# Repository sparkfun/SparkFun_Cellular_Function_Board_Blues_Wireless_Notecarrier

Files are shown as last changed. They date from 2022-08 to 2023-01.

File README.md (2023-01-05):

SparkFun MicroMod Cellular Function Board - Blues Wireless Notecarrier
===========================================================

SparkFun MicroMod Cellular Function Board Blues Wireless Notecarrier (https://www.sparkfun.com/products/20409)

[*SparkFun MicroMod Cellular Function Board - Blues Wireless Notecarrier (WRL-20409)*](https://www.sparkfun.com/products/20409)

A MicroMod Function Board that works as a Blues Wireless Notecarrier featuring the Notecard - NOTE-NBGL-500. This Function Board adds a cellular module to the MicroMod ecosystem allowing users to send and receive data from anywhere with a compatible cellular signal. The Notecard has a built-in SIM card and includes a 10 year subscription and 500MB of data included in the price. An onboard nano SIM slot is provided for users who prefer or need to use their own SIM. The Notecard module also comes with integrated cellular, SIM, onboard GPS, 3-axis accelerometer with an on-chip temperature sensor. On top of that, the Notecard features outboard device firmware updates (DFU) meaning you can reprogram a connected Processor remotely through Blues' Notehub service! There are some limitations to this process so make sure to read through the Outboard documentation in the SparkFun Hookup Guide for more information on how to properly perform Outboard device firmware updates. 

Repository Contents
-------------------

* **/Firmware/examples**
* **/Hardware**

Documentation
-------------

* **[Hookup Guide](https://learn.sparkfun.com/tutorials/cellular-function-board---blues-wireless-notecarrier)** - A standard Hookup Guide to get started with the MicroMod Cellular Function Board - Blues Wireless Notecarrier.

Product Versions
----------------

* [WRL-20409](https://www.sparkfun.com/products/20409) - Initial Release

Version History
---------------

* v1.0 - Initial release

License Information
-------------------

This product is _**open source**_! 

Please review the LICENSE.md file for license information. 

If you have any questions or concerns on licensing, please contact technical support on our [SparkFun forums](https://forum.sparkfun.com/viewforum.php?f=152).

Distributed as-is; no warranty is given.

- Your friends at SparkFun.

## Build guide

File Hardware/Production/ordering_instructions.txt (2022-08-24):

panel size, 128x137mm
PCB thickness, 0.8mm
number of layers, 2
bevel, Gold Fingers + 45° Finger Chamfered
soldermask color, Red
silkscreen color, White
oz copper, 1oz
finish, ENIG
stencils, none
pcs per panel, 6
min trace width, 0.1100mm / 0.0043in
min drill size, 0.3000mm / 0.0118in

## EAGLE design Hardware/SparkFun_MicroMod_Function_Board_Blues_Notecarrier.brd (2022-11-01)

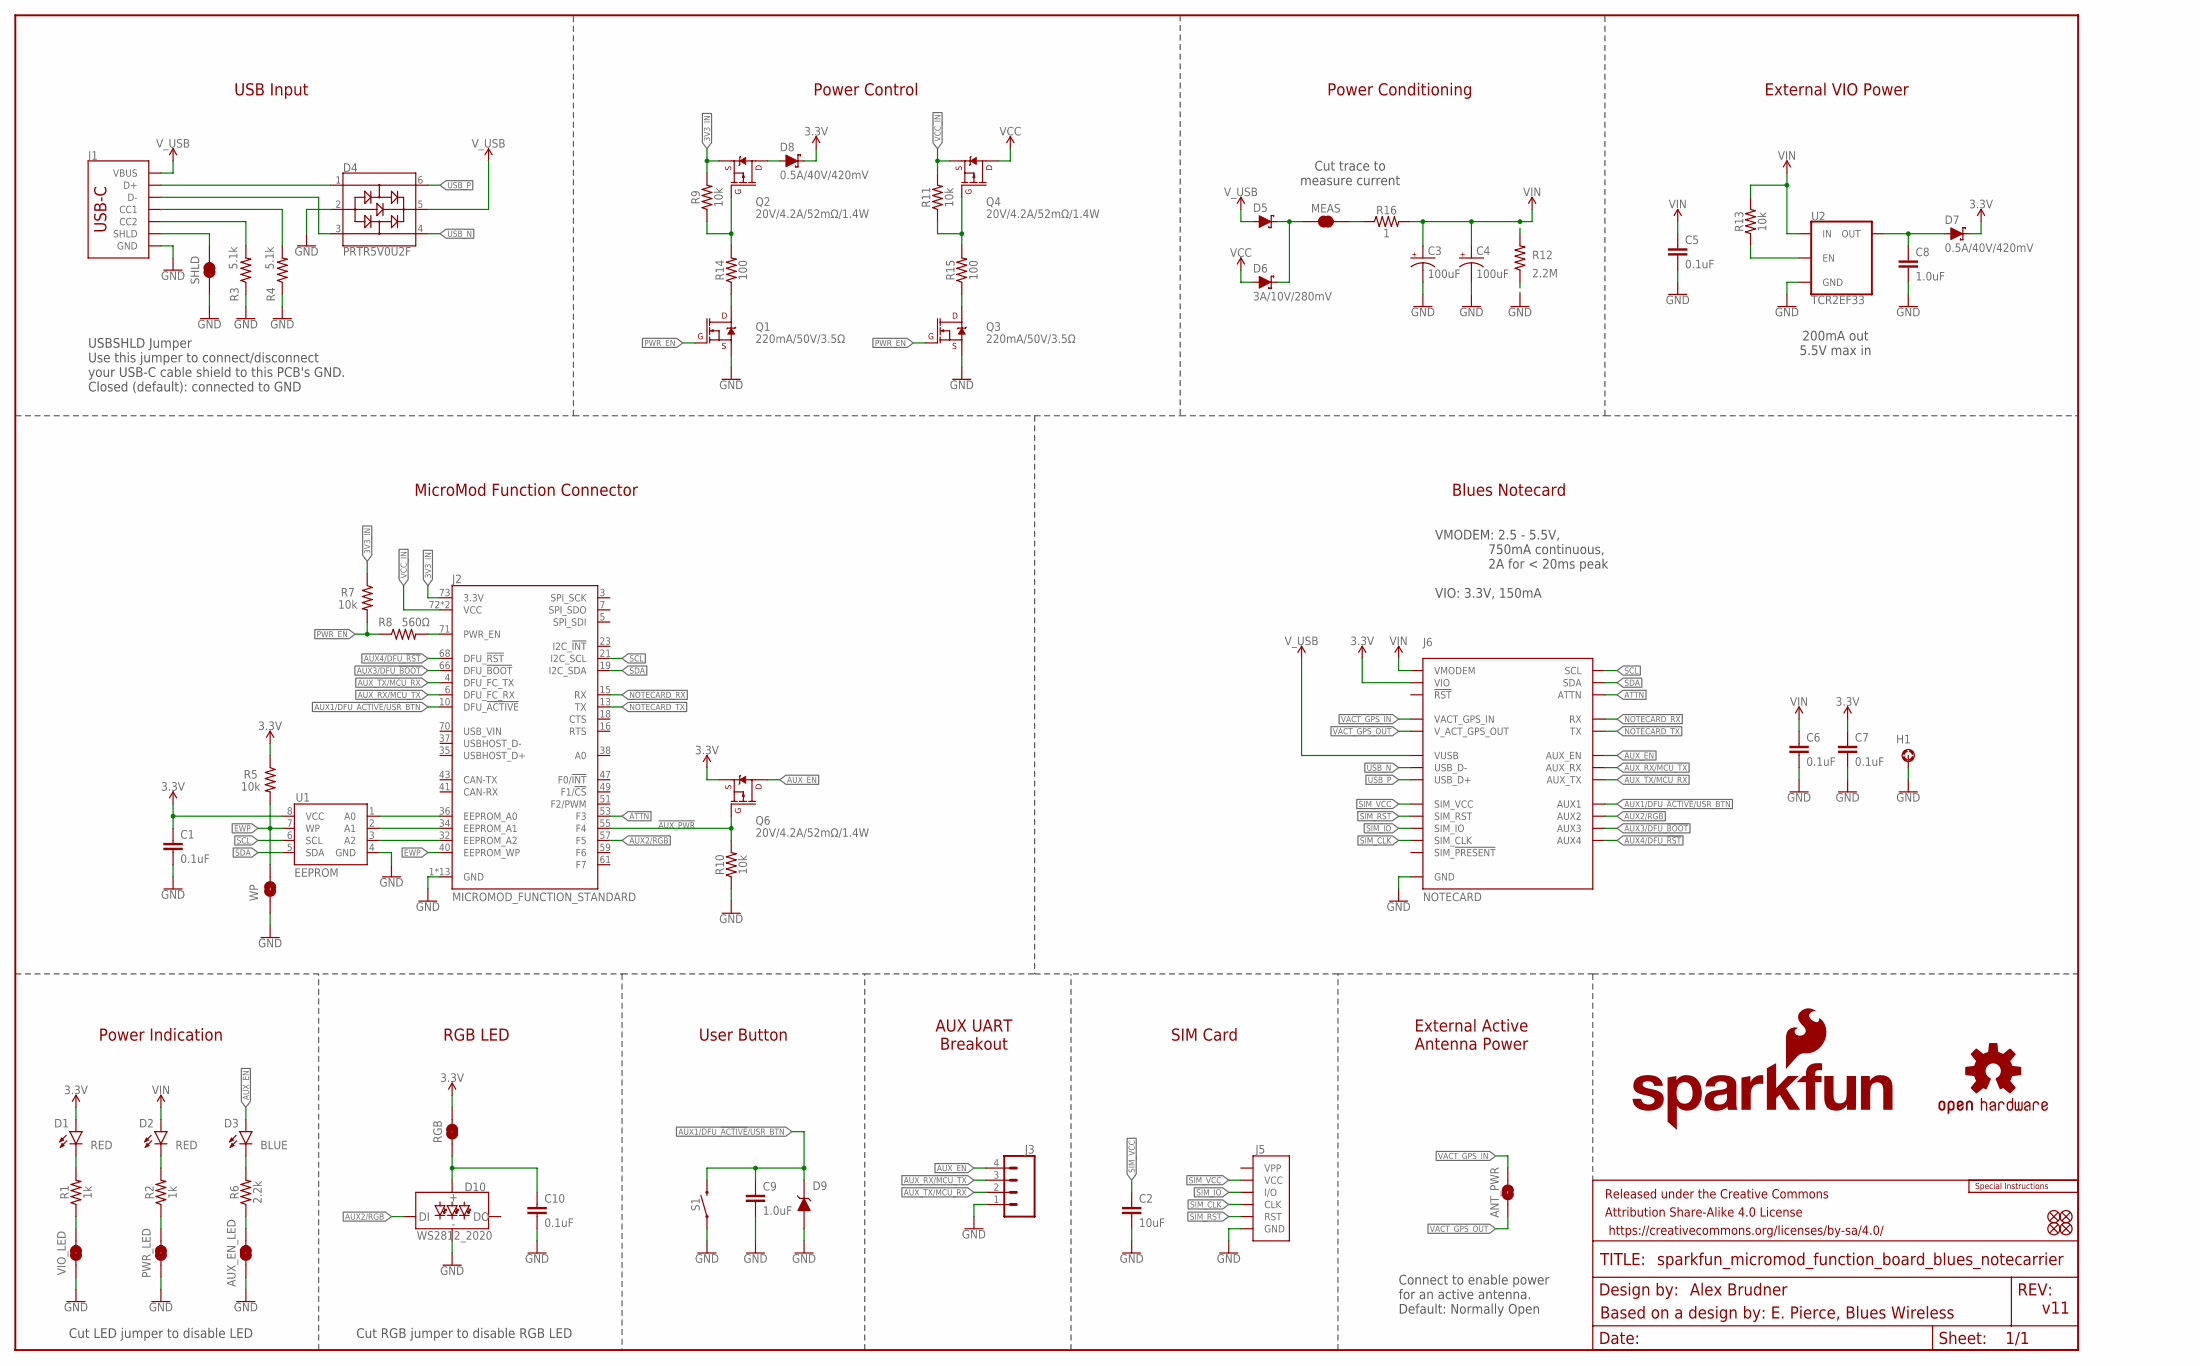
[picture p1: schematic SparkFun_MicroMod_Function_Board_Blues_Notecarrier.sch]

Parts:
ANT_PWR: JUMPER-SMT_2_NO_SILK; SMT-JUMPER_2_NO_SILK
AUX_EN_LED: JUMPER-SMT_2_NC_TRACE_SILK; SMT-JUMPER_2_NC_TRACE_SILK
C1, C5, C6, C7, C10: 0.1uF; 0402-TIGHT
C2: 10uF; 0805
C3, C4: 100uF; PANASONIC_D
C8, C9: 1.0uF; 0402-TIGHT
D1, D2: RED; LED-0603
D3: BLUE; LED-0603
D4: PRTR5V0U2F; SOT886
D5, D6: 3A/10V/280mV; SOD-323
D7, D8: 0.5A/40V/420mV; SOD-323
D9: SMBJP6KE-DNP; DO-214AA
D10: WS2812_2020; WS2812-2020
FD1, FD2, FD3, FD4: FIDUCIALUFIDUCIAL; FIDUCIAL-MICRO
FRAME1: FRAME-LEDGER; CREATIVE_COMMONS
H1: STAND-OFF-REFLOW-M2.5_2.5MM_TALL; STAND-OFF-REFLOW-M2.5
J1: USB_C_2-LAYER_PADS; USB-C-16P-2LAYER-PADS
J2: MICROMOD_FUNCTION_STANDARD; M.2-CARD-E-22_FUNCTION_STANDARD
J3: CONN_041X04_NO_SILK_NO_POP; 1X04_NO_SILK
J5: SIMHOLDER-NANOSIM-MOLEX; NANO_SIM_MOLEX_104224-0820
J6: NOTECARD; M.2-CONNECTOR-E
LOGO1: SFE_LOGO_NAME_FLAME.1_INCH; SFE_LOGO_NAME_FLAME_.1
LOGO2: SPECIAL_INSTRUCTIONS-ORDERING; ORDERING_INSTRUCTIONS
LOGO3: OSHW-LOGOMINI; OSHW-LOGO-MINI
MEAS: JUMPER-COMBO_2_NC_TRACE; COMBO-JUMPER_2_NC_TRACE
PWR_LED: JUMPER-SMT_2_NC_TRACE_SILK; SMT-JUMPER_2_NC_TRACE_SILK
Q1, Q3: 220mA/50V/3.5Ω; SOT23-3
Q2, Q4, Q6: 20V/4.2A/52mΩ/1.4W; SOT23-3
R1, R2: 1k; 0402-TIGHT
R3, R4: 5.1k; 0402-TIGHT
R5, R7, R9, R10, R11, R13: 10k; 0402-TIGHT
R6: 2.2k; 0402-TIGHT
R8: 560Ω; 0402-TIGHT
R12: 2.2M; 0402-TIGHT
R14, R15: 100; 0402-TIGHT
R16: 1; 0603
RGB: JUMPER-SMT_2_NC_TRACE_SILK; SMT-JUMPER_2_NC_TRACE_SILK
S1: MOMENTARY-SWITCH-SPST-SMD-4.6X2.8MM; TACTILE_SWITCH_SMD_4.6X2.8MM
SHLD: JUMPER-SMT_2_NC_TRACE_SILK; SMT-JUMPER_2_NC_TRACE_SILK
U1: EEPROM; SO08
U2: TCR2EF33; SOT23-5
VIO_LED: JUMPER-SMT_2_NC_TRACE_SILK; SMT-JUMPER_2_NC_TRACE_SILK
WP: JUMPER-SMT_2_NO_SILK; SMT-JUMPER_2_NO_SILK

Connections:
3.3V: C1.1, C7.1, D1.A, D7.C, D8.C, J6.2 (VIO), J6.4 (VIO), Q6.2 (S), R5.1, RGB.2, U1.8 (VCC)
3V3_IN: J2.73 (3.3V), Q2.2 (S), R7.1, R9.2
!AUX_PWR!: J2.55 (F4), Q6.1 (G), R10.2
A0: J2.36 (EEPROM_A0), U1.1 (A0)
A1: J2.34 (EEPROM_A1), U1.2 (A1)
A2: J2.32 (EEPROM_A2), U1.3 (A2)
ATTN: J2.53 (F3), J6.54 (ATTN)
AUX1/DFU_!ACTIVE!/USR_BTN: C9.1, D9.C, J2.10 (DFU_!ACTIVE!), J6.46 (AUX1), S1.3 (2), S1.4 (2)
AUX2/RGB: D10.DI, J2.57 (F5), J6.48 (AUX2)
AUX3/DFU_!BOOT!: J2.66 (DFU_!BOOT!), J6.50 (AUX3)
AUX4/DFU_!RST!: J2.68 (DFU_!RST!), J6.52 (AUX4)
AUX_EN: D3.A, J3.4, J6.56 (AUX_EN), Q6.3 (D)
AUX_RX/MCU_TX: J2.6 (DFU_FC_RX), J3.3, J6.58 (AUX_RX)
AUX_TX/MCU_RX: J2.4 (DFU_FC_TX), J3.2, J6.60 (AUX_TX)
EWP: J2.40 (EEPROM_WP), R5.2, U1.7 (WP), WP.2
GND: AUX_EN_LED.1, C1.2, C2.2, C3.-, C4.-, C5.2, C6.2, C7.2, C8.2, C9.2, C10.2, D4.2, D9.A, D10.GND, H1.1, J1.GND, J1.GND2 (GND), J2.1 (GND), J2.2 (GND), J2.8 (GND), J2.33 (GND), J2.39 (GND), J2.45 (GND), J2.75 (GND), J2.GND1 (GND), J2.GND2 (GND), J2.GND3 (GND), J2.GND4 (GND), J2.GND5 (GND), J2.GND6 (GND), J3.1, J5.G1 (GND), J5.G2 (GND), J5.G3 (GND), J5.G4 (GND), J5.S4 (GND), J6.3 (GND), J6.5 (GND), J6.6 (GND), J6.11 (GND), J6.18 (GND), J6.33 (GND), J6.39 (GND), J6.45 (GND), J6.51 (GND), J6.57 (GND), J6.71 (GND), J6.73 (GND), PWR_LED.1, Q1.2 (S), Q3.2 (S), R3.1, R4.1, R10.1, R12.1, S1.1, S1.2 (1), SHLD.1, U1.4 (GND), U2.2 (GND), VIO_LED.1, WP.1
unnamed: J2.71 (PWR_EN), R8.2
unnamed: Q2.1 (G), R9.1, R14.2
unnamed: Q4.1 (G), R11.1, R15.2
unnamed: D1.C, R1.2
unnamed: R13.1, U2.3 (EN)
unnamed: D2.C, R2.2
unnamed: D8.A, Q2.3 (D)
unnamed: J1.B5 (CC2), R3.2
unnamed: J1.A5 (CC1), R4.2
unnamed: C8.1, D7.A, U2.5 (OUT)
unnamed: PWR_LED.2, R2.1
unnamed: R1.1, VIO_LED.2
unnamed: D3.C, R6.2
unnamed: AUX_EN_LED.2, R6.1
unnamed: Q1.3 (D), R14.1
unnamed: Q3.3 (D), R15.1
unnamed: MEAS.2, MEAS.4 (2), R16.1
unnamed: C10.1, D10.VCC, RGB.1
unnamed: D5.C, D6.C, MEAS.1, MEAS.3 (1)
NOTECARD_RX: J2.15 (RX), J6.62 (RX)
NOTECARD_TX: J2.13 (TX), J6.64 (TX)
PWR_EN: Q1.1 (G), Q3.1 (G), R7.2, R8.1
SCL: J2.21 (I2C_SCL), J6.40 (SCL), U1.6 (SCL)
SDA: J2.19 (I2C_SDA), J6.42 (SDA), U1.5 (SDA)
SHLD: J1.SHLD1 (SHLD), J1.SHLD2 (SHLD), J1.SHLD3 (SHLD), J1.SHLD4 (SHLD), SHLD.2
SIM_CLK: J5.S3 (CLK), J6.14 (SIM_CLK)
SIM_IO: J5.S6 (I/O), J6.12 (SIM_IO)
SIM_RST: J5.S2 (RST), J6.10 (SIM_RST)
SIM_VCC: C2.1, J5.S1 (VCC), J6.8 (SIM_VCC)
USB_IN_N: D4.3, J1.A7 (D-), J1.B7 (D-)
USB_IN_P: D4.1, J1.A6 (D+), J1.B6 (D+)
USB_N: D4.4, J6.9 (USB_D-)
USB_P: D4.6, J6.7 (USB_D+)
VACT_GPS_IN: ANT_PWR.2, J6.22 (VACT_GPS_IN)
VACT_GPS_OUT: ANT_PWR.1, J6.20 (V_ACT_GPS_OUT)
VCC: D6.A, Q4.3 (D)
VCC_IN: J2.72 (VCC), J2.74 (VCC), Q4.2 (S), R11.2
VIN: C3.+, C4.+, C5.1, C6.1, D2.A, J6.70 (VMODEM), J6.72 (VMODEM), J6.74 (VMODEM), R12.2, R13.2, R16.2, U2.1 (IN)
V_USB: D4.5, D5.A, J1.VBUS1 (VBUS), J1.VBUS2 (VBUS), J6.13 (VUSB)

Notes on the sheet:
Alex Brudner
Based on a design by: E. Pierce, Blues Wireless
v11
MicroMod Function Connector
Power Control
USB Input
Power Conditioning
Blues Notecard
Power Indication
User Button
AUX UART Breakout
SIM Card
External Active Antenna Power
External VIO Power
200mA out 5.5V max in
VMODEM: 2.5 - 5.5V, 750mA continuous, 2A for < 20ms peak VIO: 3.3V, 150mA
USBSHLD Jumper Use this jumper to connect/disconnect your USB-C cable shield to this PCB's GND. Closed (default): connected to GND
Cut LED jumper to disable LED
Cut trace to measure current
Connect to enable power for an active antenna. Default: Normally Open
RGB LED
Cut RGB jumper to disable RGB LED

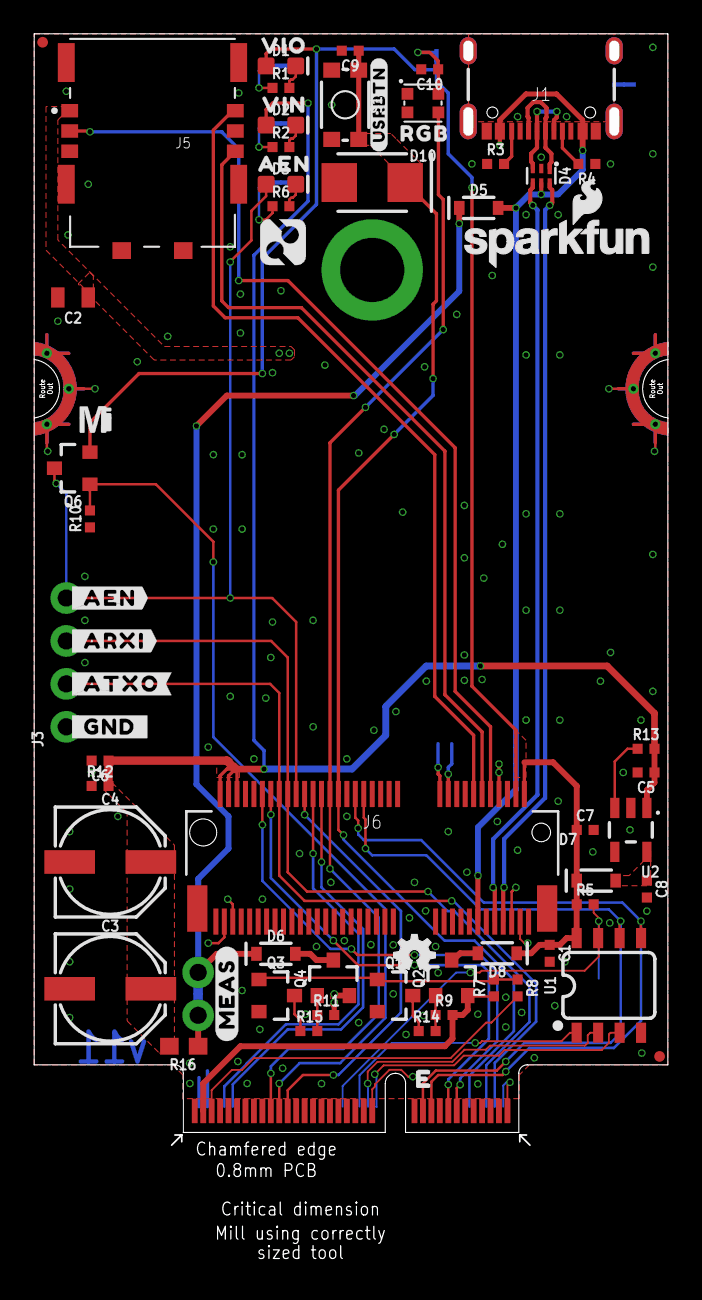
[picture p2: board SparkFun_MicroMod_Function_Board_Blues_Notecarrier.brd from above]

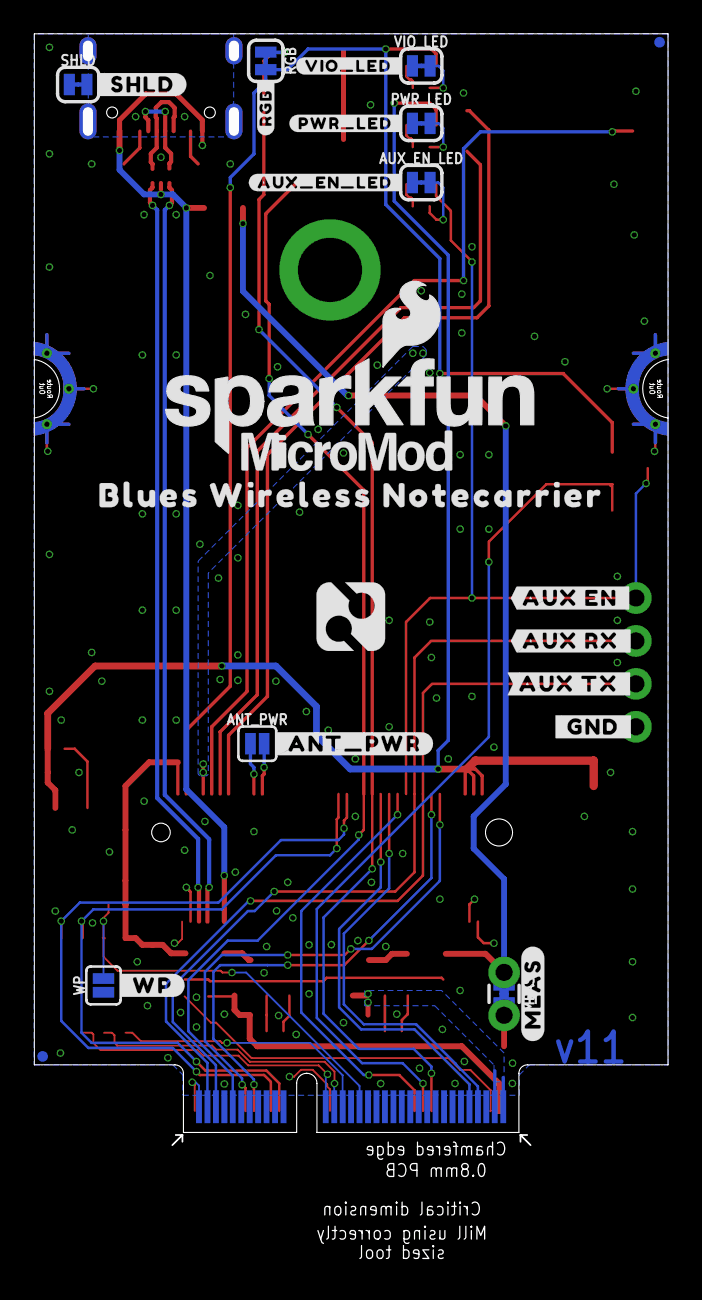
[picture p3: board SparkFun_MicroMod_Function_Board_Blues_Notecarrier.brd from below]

Board: 2 copper layers, 37.5 x 65.8 mm, 95 parts (26 on the bottom side), 55 nets.

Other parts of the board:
U$1: AEN1
U$2: VIN3
U$3: VIO4
U$4: #VIO_LED_#21
U$5: #_ARXI#0
U$6: SFE_LOGO_FLAME_STOP_.1
U$7: #_GND_#0
U$8: #_WP#2
U$9: BLUES_WIRELESS_NOTECARRIER0
U$10: NOTEHUB_BLUES#SVG7
U$11: #_ATXO#0
U$12: #AUX_TX_#0
U$13: #_AEN#0
U$14: SFE_LOGO_NAME_FLAME_.2
U$15: #AUX_RX_#0
U$16, U$17: #MEAS#4
U$18: #_ANT_PWR#5
U$19: #AUX_EN_LED_#20
U$20: #_SHLD#23
U$21: #PWR_LED_#17
U$22: #_GND_#24
U$23: NOTEHUB_BLUES#SVG5
U$24: #RGB_#0
U$25: #USRBTN#0
U$26: RGB0
U$29: MICROMOD_MI_LOGO_.35
U$30: #AUX_EN_#0
U$31: MICROMOD_LOGO_.5

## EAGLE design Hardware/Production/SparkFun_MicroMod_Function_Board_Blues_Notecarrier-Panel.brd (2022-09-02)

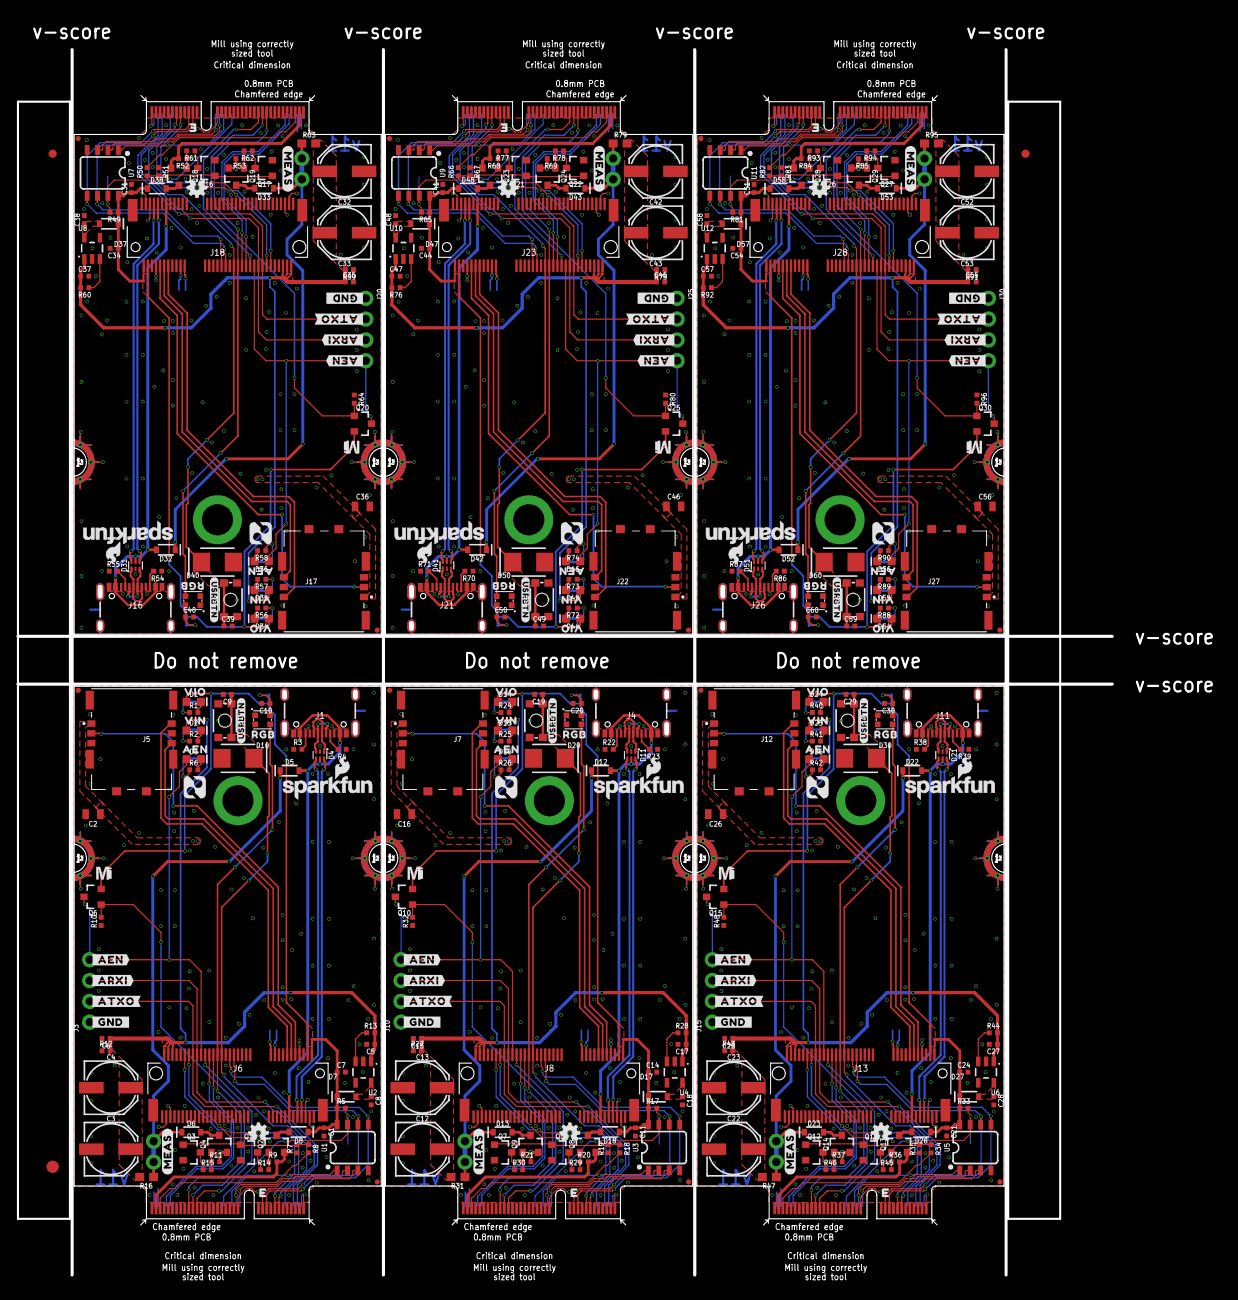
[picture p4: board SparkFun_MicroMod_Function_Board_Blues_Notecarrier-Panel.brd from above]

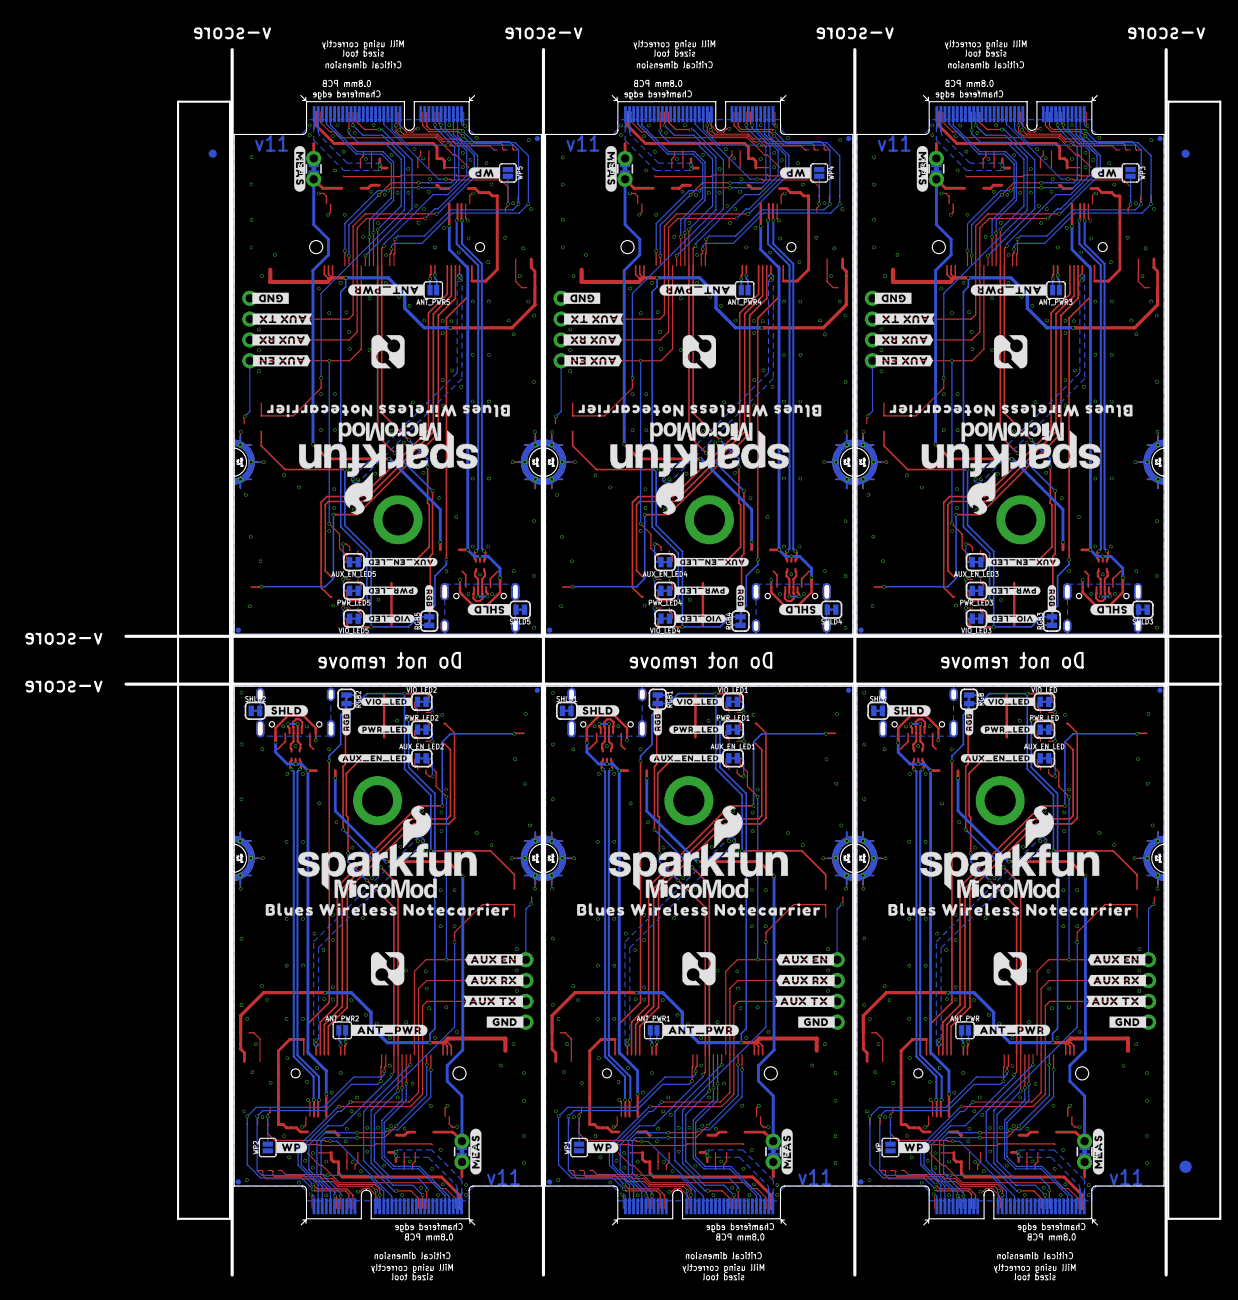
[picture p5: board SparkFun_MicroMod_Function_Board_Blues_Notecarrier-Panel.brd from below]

Board: 2 copper layers, 133.6 x 149.6 mm, 564 parts (159 on the bottom side), 330 nets.

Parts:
ANT_PWR, ANT_PWR1, ANT_PWR2, ANT_PWR3, ANT_PWR4, ANT_PWR5: JUMPER-SMT_2_NO_SILK; SMT-JUMPER_2_NO_SILK
AUX_EN_LED, AUX_EN_LED1, AUX_EN_LED2, AUX_EN_LED3, AUX_EN_LED4, AUX_EN_LED5: JUMPER-SMT_2_NC_TRACE_SILK; SMT-JUMPER_2_NC_TRACE_SILK
C1, C5, C6, C7, C10, C11, C14, C15, C17, C20, C21, C24, C25, C27, C30, C31, C34, C35, C37, C40, C41, C44, C45, C47, C50, C51, C54, C55, C57, C60: 0.1uF; 0402-TIGHT
C2, C16, C26, C36, C46, C56: 10uF; 0805
C3, C4, C12, C13, C22, C23, C32, C33, C42, C43, C52, C53: 100uF; PANASONIC_D
C8, C9, C18, C19, C28, C29, C38, C39, C48, C49, C58, C59: 1.0uF; 0402-TIGHT
D1, D2, D14, D15, D24, D25, D34, D35, D44, D45, D54, D55: RED; LED-0603
D3, D16, D26, D36, D46, D56: BLUE; LED-0603
D4, D11, D21, D31, D41, D51: PRTR5V0U2F; SOT886
D5, D6, D12, D13, D22, D23, D32, D33, D42, D43, D52, D53: 3A/10V/280mV; SOD-323
D7, D8, D17, D18, D27, D28, D37, D38, D47, D48, D57, D58: 0.5A/40V/420mV; SOD-323
D9, D19, D29, D39, D49, D59: SMBJP6KE6.8A-TP; DO-214AA
D10, D20, D30, D40, D50, D60: WS2812_2020; WS2812-2020
E$1, E$2, E$3, E$4: FIDUCIAL-1X2
E$5, E$6: FIDUCIAL-1.5X3
FD1, FD2, FD3, FD4, FD5, FD6, FD7, FD8, FD9, FD10, FD11, FD12, FD13, FD14, FD15, FD16, FD17, FD18, FD19, FD20, FD21, FD22, FD23, FD24: FIDUCIALUFIDUCIAL; FIDUCIAL-MICRO
H1, H2, H3, H4, H5, H6: STAND-OFF-REFLOW-M2.5_2.5MM_TALL; STAND-OFF-REFLOW-M2.5
J1, J4, J11, J16, J21, J26: USB-C-16P-2LAYER-PADS
J2, J9, J14, J19, J24, J29: MICROMOD_FUNCTION_STANDARD; M.2-CARD-E-22_FUNCTION_STANDARD
J3, J10, J15, J20, J25, J30: 1X04_NO_SILK
J5, J7, J12, J17, J22, J27: NANO_SIM_MOLEX_104224-0820
J6, J8, J13, J18, J23, J28: NOTECARD; M.2-CONNECTOR-E
LOGO1, LOGO4, LOGO6, LOGO8, LOGO10, LOGO12: SFE_LOGO_NAME_FLAME.1_INCH; SFE_LOGO_NAME_FLAME_.1
LOGO2, LOGO3, LOGO5, LOGO7, LOGO9, LOGO11: OSHW-LOGOMINI; OSHW-LOGO-MINI
MEAS, MEAS1, MEAS2, MEAS3, MEAS4, MEAS5: JUMPER-COMBO_2_NC_TRACE; COMBO-JUMPER_2_NC_TRACE
PWR_LED, PWR_LED1, PWR_LED2, PWR_LED3, PWR_LED4, PWR_LED5: JUMPER-SMT_2_NC_TRACE_SILK; SMT-JUMPER_2_NC_TRACE_SILK
Q1, Q3, Q5, Q7, Q11, Q12, Q16, Q17, Q21, Q22, Q26, Q27: 220mA/50V/3.5Ω; SOT23-3
Q2, Q4, Q6, Q8, Q9, Q10, Q13, Q14, Q15, Q18, Q19, Q20, Q23, Q24, Q25, Q28, Q29, Q30: 20V/4.2A/52mΩ/1.4W; SOT23-3
R1, R2, R24, R25, R40, R41, R56, R57, R72, R73, R88, R89: 1k; 0402-TIGHT
R3, R4, R22, R23, R38, R39, R54, R55, R70, R71, R86, R87: 5.1k; 0402-TIGHT
R5, R7, R9, R10, R11, R13, R17, R19, R20, R21, R28, R32, R33, R35, R36, R37, R44, R48, R49, R51, R52, R53, R60, R64, R65, R67, R68, R69, R76, R80, R81, R83, R84, R85, R92, R96: 10k; 0402-TIGHT
R6, R26, R42, R58, R74, R90: 2.2k; 0402-TIGHT
R8, R18, R34, R50, R66, R82: 560Ω; 0402-TIGHT
R12, R27, R43, R59, R75, R91: 2.2M; 0402-TIGHT
R14, R15, R29, R30, R45, R46, R61, R62, R77, R78, R93, R94: 100; 0402-TIGHT
R16, R31, R47, R63, R79, R95: 1; 0603
RGB, RGB1, RGB2, RGB3, RGB4, RGB5: JUMPER-SMT_2_NC_TRACE_SILK; SMT-JUMPER_2_NC_TRACE_SILK
S1, S2, S3, S4, S5, S6: MOMENTARY-SWITCH-SPST-SMD-4.6X2.8MM; TACTILE_SWITCH_SMD_4.6X2.8MM
SHLD, SHLD1, SHLD2, SHLD3, SHLD4, SHLD5: JUMPER-SMT_2_NC_TRACE_SILK; SMT-JUMPER_2_NC_TRACE_SILK
U1, U3, U5, U7, U9, U11: EEPROM; SO08
U2, U4, U6, U8, U10, U12: TCR2EF33; SOT23-5
U$1, U$27, U$59, U$88, U$117, U$146: AEN1
U$2, U$28, U$60, U$89, U$118, U$147: VIN3
U$3, U$32, U$61, U$90, U$119, U$148: VIO4
U$4, U$42, U$71, U$100, U$129, U$158: #VIO_LED_#21
U$5, U$53, U$82, U$111, U$140, U$169: #_ARXI#0
U$6, U$33, U$62, U$91, U$120, U$149: SFE_LOGO_FLAME_STOP_.1
U$7, U$34, U$63, U$92, U$121, U$150: #_GND_#0
U$8, U$36, U$65, U$94, U$123, U$152: #_WP#2
U$9, U$49, U$78, U$107, U$136, U$165: BLUES_WIRELESS_NOTECARRIER0
U$10, U$50, U$79, U$108, U$137, U$166: NOTEHUB_BLUES#SVG7
U$11, U$54, U$83, U$112, U$141, U$170: #_ATXO#0
U$12, U$51, U$80, U$109, U$138, U$167: #AUX_TX_#0
U$13, U$55, U$84, U$113, U$142, U$171: #_AEN#0
U$14, U$35, U$64, U$93, U$122, U$151: SFE_LOGO_NAME_FLAME_.2
U$15, U$52, U$81, U$110, U$139, U$168: #AUX_RX_#0
U$16, U$17, U$37, U$38, U$66, U$67, U$95, U$96, U$124, U$125, U$153, U$154: #MEAS#4
U$18, U$39, U$68, U$97, U$126, U$155: #_ANT_PWR#5
U$19, U$41, U$70, U$99, U$128, U$157: #AUX_EN_LED_#20
U$20, U$43, U$72, U$101, U$130, U$159: #_SHLD#23
U$21, U$40, U$69, U$98, U$127, U$156: #PWR_LED_#17
U$22, U$44, U$73, U$102, U$131, U$160: #_GND_#24
U$23, U$47, U$76, U$105, U$134, U$163: NOTEHUB_BLUES#SVG5
U$24, U$56, U$85, U$114, U$143, U$172: #RGB_#0
U$25, U$57, U$86, U$115, U$144, U$173: #USRBTN#0
U$26, U$58, U$87, U$116, U$145, U$174: RGB0
U$29, U$45, U$74, U$103, U$132, U$161: MICROMOD_MI_LOGO_.35
U$30, U$46, U$75, U$104, U$133, U$162: #AUX_EN_#0
U$31, U$48, U$77, U$106, U$135, U$164: MICROMOD_LOGO_.5
VIO_LED, VIO_LED1, VIO_LED2, VIO_LED3, VIO_LED4, VIO_LED5: JUMPER-SMT_2_NC_TRACE_SILK; SMT-JUMPER_2_NC_TRACE_SILK
WP, WP1, WP2, WP3, WP4, WP5: JUMPER-SMT_2_NO_SILK; SMT-JUMPER_2_NO_SILK

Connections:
3.3V: C1.1, C7.1, D1.A, D7.C, D8.C, J6.2, J6.4, Q6.2, R5.1, RGB.2, U1.8
3.3V1: C11.1, C14.1, D14.A, D17.C, D18.C, J8.2, J8.4, Q10.2, R17.1, RGB1.2, U3.8
3.3V2: C21.1, C24.1, D24.A, D27.C, D28.C, J13.2, J13.4, Q15.2, R33.1, RGB2.2, U5.8
3.3V3: C31.1, C34.1, D34.A, D37.C, D38.C, J18.2, J18.4, Q20.2, R49.1, RGB3.2, U7.8
3.3V4: C41.1, C44.1, D44.A, D47.C, D48.C, J23.2, J23.4, Q25.2, R65.1, RGB4.2, U9.8
3.3V5: C51.1, C54.1, D54.A, D57.C, D58.C, J28.2, J28.4, Q30.2, R81.1, RGB5.2, U11.8
3V3_IN: J2.73, Q2.2, R7.1, R9.2
3V3_IN1: J9.73, Q8.2, R19.1, R20.2
3V3_IN2: J14.73, Q13.2, R35.1, R36.2
3V3_IN3: J19.73, Q18.2, R51.1, R52.2
3V3_IN4: J24.73, Q23.2, R67.1, R68.2
3V3_IN5: J29.73, Q28.2, R83.1, R84.2
!AUX_PWR!: J2.55, Q6.1, R10.2
!AUX_PWR!1: J9.55, Q10.1, R32.2
!AUX_PWR!2: J14.55, Q15.1, R48.2
!AUX_PWR!3: J19.55, Q20.1, R64.2
!AUX_PWR!4: J24.55, Q25.1, R80.2
!AUX_PWR!5: J29.55, Q30.1, R96.2
A0: J2.36, U1.1
A1: J2.34, U1.2
A2: J2.32, U1.3
A3: J9.36, U3.1
A4: J9.32, U3.3
A5: J9.34, U3.2
A6: J14.36, U5.1
A7: J14.32, U5.3
A8: J14.34, U5.2
A9: J19.36, U7.1
A10: J19.32, U7.3
A11: J19.34, U7.2
A12: J24.36, U9.1
A13: J24.32, U9.3
A14: J24.34, U9.2
A15: J29.36, U11.1
A16: J29.32, U11.3
A17: J29.34, U11.2
ATTN: J2.53, J6.54
ATTN1: J8.54, J9.53
ATTN2: J13.54, J14.53
ATTN3: J18.54, J19.53
ATTN4: J23.54, J24.53
ATTN5: J28.54, J29.53
AUX1/DFU_!ACTIVE!/USR_BTN: C9.1, D9.C, J2.10, J6.46, S1.3, S1.4
AUX1/DFU_!ACTIVE!/USR_BTN1: C19.1, D19.C, J8.46, J9.10, S2.3, S2.4
AUX1/DFU_!ACTIVE!/USR_BTN2: C29.1, D29.C, J13.46, J14.10, S3.3, S3.4
AUX1/DFU_!ACTIVE!/USR_BTN3: C39.1, D39.C, J18.46, J19.10, S4.3, S4.4
AUX1/DFU_!ACTIVE!/USR_BTN4: C49.1, D49.C, J23.46, J24.10, S5.3, S5.4
AUX1/DFU_!ACTIVE!/USR_BTN5: C59.1, D59.C, J28.46, J29.10, S6.3, S6.4
AUX2/RGB: D10.DI, J2.57, J6.48
AUX2/RGB1: D20.DI, J8.48, J9.57
AUX2/RGB2: D30.DI, J13.48, J14.57
AUX2/RGB3: D40.DI, J18.48, J19.57
AUX2/RGB4: D50.DI, J23.48, J24.57
AUX2/RGB5: D60.DI, J28.48, J29.57
AUX3/DFU_!BOOT!: J2.66, J6.50
AUX3/DFU_!BOOT!1: J8.50, J9.66
AUX3/DFU_!BOOT!2: J13.50, J14.66
AUX3/DFU_!BOOT!3: J18.50, J19.66
AUX3/DFU_!BOOT!4: J23.50, J24.66
AUX3/DFU_!BOOT!5: J28.50, J29.66
AUX4/DFU_!RST!: J2.68, J6.52
AUX4/DFU_!RST!1: J8.52, J9.68
AUX4/DFU_!RST!2: J13.52, J14.68
AUX4/DFU_!RST!3: J18.52, J19.68
AUX4/DFU_!RST!4: J23.52, J24.68
AUX4/DFU_!RST!5: J28.52, J29.68
AUX_EN: D3.A, J3.4, J6.56, Q6.3
AUX_EN1: D16.A, J8.56, J10.4, Q10.3
AUX_EN2: D26.A, J13.56, J15.4, Q15.3
AUX_EN3: D36.A, J18.56, J20.4, Q20.3
AUX_EN4: D46.A, J23.56, J25.4, Q25.3
AUX_EN5: D56.A, J28.56, J30.4, Q30.3
AUX_RX/MCU_TX: J2.6, J3.3, J6.58
AUX_RX/MCU_TX1: J8.58, J9.6, J10.3
AUX_RX/MCU_TX2: J13.58, J14.6, J15.3
AUX_RX/MCU_TX3: J18.58, J19.6, J20.3
AUX_RX/MCU_TX4: J23.58, J24.6, J25.3
AUX_RX/MCU_TX5: J28.58, J29.6, J30.3
AUX_TX/MCU_RX: J2.4, J3.2, J6.60
AUX_TX/MCU_RX1: J8.60, J9.4, J10.2
AUX_TX/MCU_RX2: J13.60, J14.4, J15.2
AUX_TX/MCU_RX3: J18.60, J19.4, J20.2
AUX_TX/MCU_RX4: J23.60, J24.4, J25.2
AUX_TX/MCU_RX5: J28.60, J29.4, J30.2
EWP: J2.40, R5.2, U1.7, WP.2
EWP1: J9.40, R17.2, U3.7, WP1.2
EWP2: J14.40, R33.2, U5.7, WP2.2
EWP3: J19.40, R49.2, U7.7, WP3.2
EWP4: J24.40, R65.2, U9.7, WP4.2
EWP5: J29.40, R81.2, U11.7, WP5.2
GND: AUX_EN_LED.1, C1.2, C2.2, C3.-, C4.-, C5.2, C6.2, C7.2, C8.2, C9.2, C10.2, D4.2, D9.A, D10.GND, H1.1, J1.GND, J1.GND2, J2.1, J2.2, J2.8, J2.33, J2.39, J2.45, J2.75, J2.GND1, J2.GND2, J2.GND3, J2.GND4, J2.GND5, J2.GND6, J3.1, J5.G1, J5.G2, J5.G3, J5.G4, J5.S4, J6.3, J6.5, J6.6, J6.11, J6.18, J6.33, J6.39, J6.45, J6.51, J6.57, J6.71, J6.73, PWR_LED.1, Q1.2, Q3.2, R3.1, R4.1, R10.1, R12.1, S1.1, S1.2, SHLD.1, U1.4, U2.2, VIO_LED.1, WP.1
GND1: AUX_EN_LED1.1, C11.2, C12.-, C13.-, C14.2, C15.2, C16.2, C17.2, C18.2, C19.2, C20.2, D11.2, D19.A, D20.GND, H2.1, J4.GND, J4.GND2, J7.G1, J7.G2, J7.G3, J7.G4, J7.S4, J8.3, J8.5, J8.6, J8.11, J8.18, J8.33, J8.39, J8.45, J8.51, J8.57, J8.71, J8.73, J9.1, J9.2, J9.8, J9.33, J9.39, J9.45, J9.75, J9.GND1, J9.GND2, J9.GND3, J9.GND4, J9.GND5, J9.GND6, J10.1, PWR_LED1.1, Q5.2, Q7.2, R22.1, R23.1, R27.1, R32.1, S2.1, S2.2, SHLD1.1, U3.4, U4.2, VIO_LED1.1, WP1.1
GND2: AUX_EN_LED2.1, C21.2, C22.-, C23.-, C24.2, C25.2, C26.2, C27.2, C28.2, C29.2, C30.2, D21.2, D29.A, D30.GND, H3.1, J11.GND, J11.GND2, J12.G1, J12.G2, J12.G3, J12.G4, J12.S4, J13.3, J13.5, J13.6, J13.11, J13.18, J13.33, J13.39, J13.45, J13.51, J13.57, J13.71, J13.73, J14.1, J14.2, J14.8, J14.33, J14.39, J14.45, J14.75, J14.GND1, J14.GND2, J14.GND3, J14.GND4, J14.GND5, J14.GND6, J15.1, PWR_LED2.1, Q11.2, Q12.2, R38.1, R39.1, R43.1, R48.1, S3.1, S3.2, SHLD2.1, U5.4, U6.2, VIO_LED2.1, WP2.1
GND3: AUX_EN_LED3.1, C31.2, C32.-, C33.-, C34.2, C35.2, C36.2, C37.2, C38.2, C39.2, C40.2, D31.2, D39.A, D40.GND, H4.1, J16.GND, J16.GND2, J17.G1, J17.G2, J17.G3, J17.G4, J17.S4, J18.3, J18.5, J18.6, J18.11, J18.18, J18.33, J18.39, J18.45, J18.51, J18.57, J18.71, J18.73, J19.1, J19.2, J19.8, J19.33, J19.39, J19.45, J19.75, J19.GND1, J19.GND2, J19.GND3, J19.GND4, J19.GND5, J19.GND6, J20.1, PWR_LED3.1, Q16.2, Q17.2, R54.1, R55.1, R59.1, R64.1, S4.1, S4.2, SHLD3.1, U7.4, U8.2, VIO_LED3.1, WP3.1
GND4: AUX_EN_LED4.1, C41.2, C42.-, C43.-, C44.2, C45.2, C46.2, C47.2, C48.2, C49.2, C50.2, D41.2, D49.A, D50.GND, H5.1, J21.GND, J21.GND2, J22.G1, J22.G2, J22.G3, J22.G4, J22.S4, J23.3, J23.5, J23.6, J23.11, J23.18, J23.33, J23.39, J23.45, J23.51, J23.57, J23.71, J23.73, J24.1, J24.2, J24.8, J24.33, J24.39, J24.45, J24.75, J24.GND1, J24.GND2, J24.GND3, J24.GND4, J24.GND5, J24.GND6, J25.1, PWR_LED4.1, Q21.2, Q22.2, R70.1, R71.1, R75.1, R80.1, S5.1, S5.2, SHLD4.1, U9.4, U10.2, VIO_LED4.1, WP4.1
GND5: AUX_EN_LED5.1, C51.2, C52.-, C53.-, C54.2, C55.2, C56.2, C57.2, C58.2, C59.2, C60.2, D51.2, D59.A, D60.GND, H6.1, J26.GND, J26.GND2, J27.G1, J27.G2, J27.G3, J27.G4, J27.S4, J28.3, J28.5, J28.6, J28.11, J28.18, J28.33, J28.39, J28.45, J28.51, J28.57, J28.71, J28.73, J29.1, J29.2, J29.8, J29.33, J29.39, J29.45, J29.75, J29.GND1, J29.GND2, J29.GND3, J29.GND4, J29.GND5, J29.GND6, J30.1, PWR_LED5.1, Q26.2, Q27.2, R86.1, R87.1, R91.1, R96.1, S6.1, S6.2, SHLD5.1, U11.4, U12.2, VIO_LED5.1, WP5.1
unnamed: J2.71, R8.2
unnamed: Q2.1, R9.1, R14.2
unnamed: Q4.1, R11.1, R15.2
unnamed: D1.C, R1.2
unnamed: R13.1, U2.3
unnamed: D2.C, R2.2
unnamed: D8.A, Q2.3
unnamed: J1.B5, R3.2
unnamed: J1.A5, R4.2
unnamed: C8.1, D7.A, U2.5
unnamed: PWR_LED.2, R2.1
unnamed: R1.1, VIO_LED.2
unnamed: D3.C, R6.2
unnamed: AUX_EN_LED.2, R6.1
unnamed: Q1.3, R14.1
unnamed: Q3.3, R15.1
unnamed: MEAS.2, MEAS.4, R16.1
unnamed: C10.1, D10.VCC, RGB.1
unnamed: J9.71, R18.2
unnamed: Q8.1, R20.1, R29.2
unnamed: Q9.1, R21.1, R30.2
unnamed: J4.B5, R22.2
unnamed: J4.A5, R23.2
unnamed: D12.C, D13.C, MEAS1.1, MEAS1.3
unnamed: D14.C, R24.2
unnamed: D15.C, R25.2
unnamed: PWR_LED1.2, R25.1
unnamed: R24.1, VIO_LED1.2
unnamed: D16.C, R26.2
unnamed: AUX_EN_LED1.2, R26.1
unnamed: R28.1, U4.3
unnamed: C18.1, D17.A, U4.5
unnamed: D18.A, Q8.3
unnamed: Q5.3, R29.1
unnamed: Q7.3, R30.1
unnamed: MEAS1.2, MEAS1.4, R31.1
unnamed: D5.C, D6.C, MEAS.1, MEAS.3
unnamed: C20.1, D20.VCC, RGB1.1
unnamed: J14.71, R34.2
unnamed: Q13.1, R36.1, R45.2
unnamed: Q14.1, R37.1, R46.2
unnamed: J11.B5, R38.2
unnamed: J11.A5, R39.2
unnamed: D22.C, D23.C, MEAS2.1, MEAS2.3
unnamed: D24.C, R40.2
unnamed: D25.C, R41.2
unnamed: PWR_LED2.2, R41.1
unnamed: R40.1, VIO_LED2.2
unnamed: D26.C, R42.2
unnamed: AUX_EN_LED2.2, R42.1
unnamed: R44.1, U6.3
unnamed: C28.1, D27.A, U6.5
unnamed: D28.A, Q13.3
unnamed: Q11.3, R45.1
unnamed: Q12.3, R46.1
unnamed: MEAS2.2, MEAS2.4, R47.1
unnamed: C30.1, D30.VCC, RGB2.1
unnamed: J19.71, R50.2
unnamed: Q18.1, R52.1, R61.2
unnamed: Q19.1, R53.1, R62.2
unnamed: J16.B5, R54.2
unnamed: J16.A5, R55.2
unnamed: D32.C, D33.C, MEAS3.1, MEAS3.3
unnamed: D34.C, R56.2
unnamed: D35.C, R57.2
unnamed: PWR_LED3.2, R57.1
unnamed: R56.1, VIO_LED3.2
unnamed: D36.C, R58.2
unnamed: AUX_EN_LED3.2, R58.1
unnamed: R60.1, U8.3
unnamed: C38.1, D37.A, U8.5
unnamed: D38.A, Q18.3
unnamed: Q16.3, R61.1
unnamed: Q17.3, R62.1
unnamed: MEAS3.2, MEAS3.4, R63.1
unnamed: C40.1, D40.VCC, RGB3.1
unnamed: J24.71, R66.2
unnamed: Q23.1, R68.1, R77.2
unnamed: Q24.1, R69.1, R78.2
unnamed: J21.B5, R70.2
unnamed: J21.A5, R71.2
unnamed: D42.C, D43.C, MEAS4.1, MEAS4.3
unnamed: D44.C, R72.2
unnamed: D45.C, R73.2
unnamed: PWR_LED4.2, R73.1
unnamed: R72.1, VIO_LED4.2
unnamed: D46.C, R74.2
unnamed: AUX_EN_LED4.2, R74.1
unnamed: R76.1, U10.3
unnamed: C48.1, D47.A, U10.5
unnamed: D48.A, Q23.3
unnamed: Q21.3, R77.1
unnamed: Q22.3, R78.1
unnamed: MEAS4.2, MEAS4.4, R79.1
unnamed: C50.1, D50.VCC, RGB4.1
unnamed: J29.71, R82.2
unnamed: Q28.1, R84.1, R93.2
unnamed: Q29.1, R85.1, R94.2
unnamed: J26.B5, R86.2
unnamed: J26.A5, R87.2
unnamed: D52.C, D53.C, MEAS5.1, MEAS5.3
unnamed: D54.C, R88.2
unnamed: D55.C, R89.2
unnamed: PWR_LED5.2, R89.1
unnamed: R88.1, VIO_LED5.2
unnamed: D56.C, R90.2
unnamed: AUX_EN_LED5.2, R90.1
unnamed: R92.1, U12.3
unnamed: C58.1, D57.A, U12.5
unnamed: D58.A, Q28.3
unnamed: Q26.3, R93.1
unnamed: Q27.3, R94.1
unnamed: MEAS5.2, MEAS5.4, R95.1
unnamed: C60.1, D60.VCC, RGB5.1
NOTECARD_RX: J2.15, J6.62
NOTECARD_RX1: J8.62, J9.15
NOTECARD_RX2: J13.62, J14.15
NOTECARD_RX3: J18.62, J19.15
NOTECARD_RX4: J23.62, J24.15
NOTECARD_RX5: J28.62, J29.15
NOTECARD_TX: J2.13, J6.64
NOTECARD_TX1: J8.64, J9.13
NOTECARD_TX2: J13.64, J14.13
NOTECARD_TX3: J18.64, J19.13
NOTECARD_TX4: J23.64, J24.13
NOTECARD_TX5: J28.64, J29.13
PWR_EN: Q1.1, Q3.1, R7.2, R8.1
PWR_EN1: Q5.1, Q7.1, R18.1, R19.2
PWR_EN2: Q11.1, Q12.1, R34.1, R35.2
PWR_EN3: Q16.1, Q17.1, R50.1, R51.2
PWR_EN4: Q21.1, Q22.1, R66.1, R67.2
PWR_EN5: Q26.1, Q27.1, R82.1, R83.2
SCL: J2.21, J6.40, U1.6
SCL1: J8.40, J9.21, U3.6
SCL2: J13.40, J14.21, U5.6
SCL3: J18.40, J19.21, U7.6
SCL4: J23.40, J24.21, U9.6
SCL5: J28.40, J29.21, U11.6
SDA: J2.19, J6.42, U1.5
SDA1: J8.42, J9.19, U3.5
SDA2: J13.42, J14.19, U5.5
SDA3: J18.42, J19.19, U7.5
SDA4: J23.42, J24.19, U9.5
SDA5: J28.42, J29.19, U11.5
SHLD: J1.SHLD1, J1.SHLD2, J1.SHLD3, J1.SHLD4, SHLD.2
SHLD1: J4.SHLD1, J4.SHLD2, J4.SHLD3, J4.SHLD4, SHLD1.2
SHLD2: J11.SHLD1, J11.SHLD2, J11.SHLD3, J11.SHLD4, SHLD2.2
SHLD3: J16.SHLD1, J16.SHLD2, J16.SHLD3, J16.SHLD4, SHLD3.2
SHLD4: J21.SHLD1, J21.SHLD2, J21.SHLD3, J21.SHLD4, SHLD4.2
SHLD5: J26.SHLD1, J26.SHLD2, J26.SHLD3, J26.SHLD4, SHLD5.2
SIM_CLK: J5.S3, J6.14
SIM_CLK1: J7.S3, J8.14
SIM_CLK2: J12.S3, J13.14
SIM_CLK3: J17.S3, J18.14
SIM_CLK4: J22.S3, J23.14
SIM_CLK5: J27.S3, J28.14
SIM_IO: J5.S6, J6.12
SIM_IO1: J7.S6, J8.12
SIM_IO2: J12.S6, J13.12
SIM_IO3: J17.S6, J18.12
SIM_IO4: J22.S6, J23.12
SIM_IO5: J27.S6, J28.12
SIM_RST: J5.S2, J6.10
SIM_RST1: J7.S2, J8.10
SIM_RST2: J12.S2, J13.10
SIM_RST3: J17.S2, J18.10
SIM_RST4: J22.S2, J23.10
SIM_RST5: J27.S2, J28.10
SIM_VCC: C2.1, J5.S1, J6.8
SIM_VCC1: C16.1, J7.S1, J8.8
SIM_VCC2: C26.1, J12.S1, J13.8
SIM_VCC3: C36.1, J17.S1, J18.8
SIM_VCC4: C46.1, J22.S1, J23.8
SIM_VCC5: C56.1, J27.S1, J28.8
USB_IN_N: D4.3, J1.A7, J1.B7
USB_IN_N1: D11.3, J4.A7, J4.B7
USB_IN_N2: D21.3, J11.A7, J11.B7
USB_IN_N3: D31.3, J16.A7, J16.B7
USB_IN_N4: D41.3, J21.A7, J21.B7
USB_IN_N5: D51.3, J26.A7, J26.B7
USB_IN_P: D4.1, J1.A6, J1.B6
USB_IN_P1: D11.1, J4.A6, J4.B6
USB_IN_P2: D21.1, J11.A6, J11.B6
USB_IN_P3: D31.1, J16.A6, J16.B6
USB_IN_P4: D41.1, J21.A6, J21.B6
USB_IN_P5: D51.1, J26.A6, J26.B6
USB_N: D4.4, J6.9
USB_N1: D11.4, J8.9
USB_N2: D21.4, J13.9
USB_N3: D31.4, J18.9
USB_N4: D41.4, J23.9
USB_N5: D51.4, J28.9
USB_P: D4.6, J6.7
USB_P1: D11.6, J8.7
USB_P2: D21.6, J13.7
USB_P3: D31.6, J18.7
USB_P4: D41.6, J23.7
USB_P5: D51.6, J28.7
VACT_GPS_IN: ANT_PWR.2, J6.22
VACT_GPS_IN1: ANT_PWR1.2, J8.22
VACT_GPS_IN2: ANT_PWR2.2, J13.22
VACT_GPS_IN3: ANT_PWR3.2, J18.22
VACT_GPS_IN4: ANT_PWR4.2, J23.22
VACT_GPS_IN5: ANT_PWR5.2, J28.22
VACT_GPS_OUT: ANT_PWR.1, J6.20
VACT_GPS_OUT1: ANT_PWR1.1, J8.20
VACT_GPS_OUT2: ANT_PWR2.1, J13.20
VACT_GPS_OUT3: ANT_PWR3.1, J18.20
VACT_GPS_OUT4: ANT_PWR4.1, J23.20
VACT_GPS_OUT5: ANT_PWR5.1, J28.20
VCC: D6.A, Q4.3
VCC1: D13.A, Q9.3
VCC2: D23.A, Q14.3
VCC3: D33.A, Q19.3
VCC4: D43.A, Q24.3
VCC5: D53.A, Q29.3
VCC_IN: J2.72, J2.74, Q4.2, R11.2
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

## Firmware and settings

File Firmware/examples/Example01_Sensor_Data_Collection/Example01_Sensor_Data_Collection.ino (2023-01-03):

/**
 * @file
 * @brief This example collects sensor data and posts it to NoteHub.
 * @copyright SPDX-License-Identifier: MIT
 * @author Alex Brudner, SparkFun Electronics
 * @date 2022-11-02
 * @note Based on Example01 from the MicroMod Environmental Function Board by 
 * Ho Yun "Bobby" Chan. This example code combines example codes from the 
 * SHTC3, STC31, and SGP40 libraries. Most of the steps to obtain the 
 * measurements are the same as the example code. Generic object names were 
 * renamed (e.g. mySensor => mySGP40 and mySTC3x).
 *
 *    Example 1: Basic Relative Humidity and Temperature Readings  w/ SHTC3
 *       Written by Owen Lyke
 *    Example 2: PHT (SHTC3) Compensated CO2 Readings w/ STC31
 *       Written by Paul Clark and based on earlier code by Nathan Seidle
 *    Example 1: Basic VOC Index w/ SGP40
 *       Written by Paul Clark
 *
 * Open a Serial Monitor at 115200 baud to view the readings too!
 *
 * Note: You may need to wait about ~5 minutes after starting up the code 
 * before VOC index
 * has any values.
 *
 * ========== HARDWARE CONNECTIONS ==========
 * MicroMod STM32 Processor Board => MicroMod Main Board => MicroMod 
 *  Environmental Function Board (with SHTC3, STC31, and SGP40)
 * MicroMod STM32 Processor Board => MicroMod Main Board => MicroMod 
 *  Function Board Blues Wireless Notecarrier
 *
 * Feel like supporting open source hardware?
 * Buy a board from SparkFun!
 *      MicroMod Function Board Blues Wireless Notecarrier  
 *        | https://www.sparkfun.com/products/20409
 *      MicroMod STM32 Processor                            
 *        | https://www.sparkfun.com/products/16401
 *      MicroMod Main Board - Double                        
 *        | https://www.sparkfun.com/products/18575
 *      MicroMod Environmental Function Board               
 *        | https://www.sparkfun.com/products/18632
 *
 * You can also get the sensors individually.
 *
 *      Qwiic SHTC3 | https://www.sparkfun.com/products/16467
 *      Qwiic STC31 | https://www.sparkfun.com/products/18385
 *      Qwiic SGP40 | https://www.sparkfun.com/products/17729
 */

/* Notecard Includes */
#include <Arduino.h>
#include <Wire.h>
#include <Notecard.h>

/* Sensor Includes */
#include <SparkFun_SHTC3.h>
#include <SparkFun_STC3x_Arduino_Library.h>
#include <SparkFun_SGP40_Arduino_Library.h>

#define PRODUCT_UID "com.your-company.your-name:your_product"

/* Instantiate Notecard class */
Notecard notecard;
int ncUpdateCtr = 0;

/* Instantiate sensor interface classes */
SHTC3 mySHTC3;
STC3x mySTC3x;
SGP40 mySGP40;

float rh = 0.0;           // Relative Humidity from the SHTC3
float temperature = 0.0;  // Temperature from the SHTC3
float co2 = 0.0;          // %CO2 from STC3
int32_t voc = 0;          // VOC index from SGP40

void setup() {
  /* Begin Serial communications */
  delay(2500);
  Serial.begin(115200);
  Serial.println(F("Begin - MicroMod Notecarrier Example 01: Sensor Data."));
  notecard.setDebugOutputStream(Serial);

  /* Begin I2C communications */
  Wire.begin();

  /* Initialize Notecard */
  notecard.begin();

  /* Configure Notecard */
  J *req = notecard.newRequest("hub.set");
  JAddStringToObject(req, "product", PRODUCT_UID);
  JAddStringToObject(req, "mode", "continuous");
  notecard.sendRequest(req);

  /* Find and initialize sensors */
  if (mySHTC3.begin() != SHTC3_Status_Nominal)
  {
    Serial.println(F("SHTC3 not detected. Please check wiring. Freezing..."));
    while (1)
      ; // Do nothing more
  }

  if (!mySTC3x.begin())
  {
    Serial.println(F("STC3x not detected. Please check wiring. Freezing..."));
    while (1)
      ; // Do nothing more
  }

  if (!mySGP40.begin())
  {
    Serial.println(F("SGP40 not detected. Check connections. Freezing..."));
    while (1)
      ; // Do nothing more
  }

  /**
   * We need to tell the STC3x what binary gas and full range we are using
   * Possible values are:
   * STC3X_BINARY_GAS_CO2_N2_100   : Set binary gas to CO2 in N2.  
   *    Range: 0 to 100 vol%
   * STC3X_BINARY_GAS_CO2_AIR_100  : Set binary gas to CO2 in Air. 
   *    Range: 0 to 100 vol%
   * STC3X_BINARY_GAS_CO2_N2_25    : Set binary gas to CO2 in N2.  
   *    Range: 0 to 25 vol%
   * STC3X_BINARY_GAS_CO2_AIR_25   : Set binary gas to CO2 in Air. 
   *    Range: 0 to 25 vol% 
   */
  if (!mySTC3x.setBinaryGas(STC3X_BINARY_GAS_CO2_AIR_25))
  {
    Serial.println(F("ST3x - Could not set the binary gas! Freezing..."));
    while (1)
      ; // Do nothing more
  }

  /**
   * Get an initial measurement so we can compensate for temperature and 
   * relative humidity using the readings from the SHTC3 
   */
  if (mySHTC3.update() != SHTC3_Status_Nominal) // Request a measurement
  {
    Serial.println(F("Could not read the RH and T from the SHTC3! \\
Freezing..."));
    while (1)
      ; // Do nothing more
  }

  /**
   * Configure STC31 temperature compensation based on previous measurement.
   * In case the ‘Set temperature command’ has been used prior to the above 
   * measurement command, this will set a new temperature compensation point.
   */
  temperature = mySHTC3.toDegC(); 
  Serial.print(F("Setting STC3x temperature to "));
  Serial.print(temperature, 2);
  Serial.print(F("C was "));
  if (!mySTC3x.setTemperature(temperature))
    Serial.print(F("not "));
  Serial.println(F("successful"));

  /**
   * Configure STC31 humidity compensation based on previous measurement.
   * In case the ‘Set humidity command’ has been used prior to the above 
   * measurement command, this will set a new humidity compensation point.
   */
  rh = mySHTC3.toPercent();
  Serial.print(F("Setting STC3x RH to "));
  Serial.print(rh, 2);
  Serial.print(F("% was "));
  if (!mySTC3x.setRelativeHumidity(rh))
    Serial.print(F("not "));
  Serial.println(F("successful"));

  /** 
   * If we have a pressure sensor available, we can compensate for ambient 
   * pressure too.
   * As an example, let's set the pressure to 840 mbar (== SF Headquarters) 
   */
  uint16_t pressure = 840;
  Serial.print(F("Setting STC3x pressure to "));
  Serial.print(pressure);
  Serial.print(F("mbar was "));
  if (mySTC3x.setPressure(pressure) == false)
    Serial.print(F("not "));
  Serial.println(F("successful"));

  Serial.println(F("Note: Relative humidity and temperature compensation for the STC31 will be updated frequently in the main loop() function."));

}

void loop() {

  //================================
  //==========READ SHTC3============
  //================================
  /* minimum update rate = ~100Hz */

  SHTC3_Status_TypeDef result = mySHTC3.update();           // Call "update()" to command a measurement, wait for measurement to complete, and update the RH and T members of the object

  rh = mySHTC3.toPercent();                                 // "toPercent" returns the percent humidity as a floating point number
  Serial.print(F("RelH: "));
  Serial.print(rh);
  Serial.println(F("%"));

  temperature = mySHTC3.toDegC();
  Serial.print(F("T: "));
  Serial.print(temperature);
  Serial.print(F(" deg C"));

  if (mySHTC3.lastStatus == SHTC3_Status_Nominal)           // You can also assess the status of the last command by checking the ".lastStatus" member of the object
  {
    Serial.println("");                                         //Sample data good, no need to output a message
  }
  else {
    Serial.print(F(",     Update failed, error: "));        //notify user if there is an error
    errorDecoder(mySHTC3.lastStatus);
    Serial.println("");
  }



  //==============================
  //==========READ STC31==========
  //==============================
  /* minimum update rate = 1Hz */


  if (!mySTC3x.setRelativeHumidity(rh))
    Serial.print(F("Unable to set STC31 Relative Humidity with SHTC3."));

  if (!mySTC3x.setTemperature(temperature))
    Serial.println(F("Unable to set STC31 Temperature with SHTC3."));


  Serial.print(F("CO2(%): "));

  if (mySTC3x.measureGasConcentration())                   // measureGasConcentration will return true when fresh data is available
  {
    co2 = mySTC3x.getCO2();
    Serial.println(co2, 2);
  }
  else
  {
    co2 = mySTC3x.getCO2();
    Serial.print(co2, 2);
    Serial.println(F(",     (old STC3 sample reading, STC31 was not able to get fresh data yet)"));  //output this note to indicate  when we are not able to obtain a new measurement
  }



  //==============================
  //==========READ SGP40==========
  //==============================
  /* minimum update rate = 1Hz */
  Serial.print(F("VOC: "));
  voc = mySGP40.getVOCindex(rh, temperature);
  Serial.println(voc); 

  /* Update the notecard about every 15s.*/
  if(++ncUpdateCtr >= 14)
  {
    ncUpdateCtr = 0;
    //==============================
    //=========UPLOAD DATA==========
    //==============================
    J *req = notecard.newRequest("note.add");
    if (req != NULL) {
      JAddStringToObject(req, "file", "sensors.qo");
      JAddBoolToObject(req, "sync", true);

      J *body = JCreateObject();
      if (body != NULL) {
        JAddNumberToObject(body, "temperature", temperature);
        JAddNumberToObject(body, "humidity", rh);
        JAddNumberToObject(body, "CO2%", co2);
        JAddNumberToObject(body, "VOC", voc);
        JAddItemToObject(req, "body", body);
      }

      notecard.sendRequest(req);
    }    
  }

  //================================
  //=========SPACE & DELAY==========
  //================================
  Serial.println("");// Uncomment this line to add some space between readings for the Serial Monitor
  delay(1000); //Wait 1 second - the Sensirion VOC and CO2 algorithms expects a sample rate of 1Hz

}

void errorDecoder(SHTC3_Status_TypeDef message)                             // The errorDecoder function prints "SHTC3_Status_TypeDef" results in a human-friendly way
{
  switch (message)
  {
    case SHTC3_Status_Nominal : Serial.print("Nominal"); break;
    case SHTC3_Status_Error : Serial.print("Error"); break;
    case SHTC3_Status_CRC_Fail : Serial.print("CRC Fail"); break;
    default : Serial.print("Unknown return code"); break;
  }
}

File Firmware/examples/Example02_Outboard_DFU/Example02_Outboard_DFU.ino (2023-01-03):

/**
 * @file Example02_Outboard_DFU.ino
 * @brief This example performs an Outboard Device Firmware Update.
 * @copyright SPDX-License-Identifier: MIT
 * @author Alex Brudner, SparkFun Electronics
 * @date 2022-11-02
 * @note Based on the DFU example from Blues Wireless. See
 * https://github.com/blues/note-outboard-dfu
 * 
 * ========== HARDWARE CONNECTIONS ==========
 * MicroMod STM32 Processor Board => MicroMod Main Board => MicroMod 
 *  Function Board Blues Wireless Notecarrier
 *
 * Feel like supporting open source hardware?
 * Buy a board from SparkFun!
 *      MicroMod Function Board Blues Wireless Notecarrier  
 *        | https://www.sparkfun.com/products/20409
 *      MicroMod STM32 Processor                            
 *        | https://www.sparkfun.com/products/16401
 *      MicroMod Main Board - Double                        
 *        | https://www.sparkfun.com/products/18575
 */

#include <Arduino.h>
#include <Notecard.h>

#define PRODUCT_UID "com.your-company.your-name:your_product"

int ledPin = LED_BUILTIN;

Notecard notecard;

void setup()
{
    pinMode(ledPin, OUTPUT);
    
    /* Begin Serial communications */
    Serial.begin(115200);
    Serial.println(F("Begin - MicroMod Notecarrier Example 02: Outboard DFU"));
    notecard.setDebugOutputStream(Serial);

    /* Begin Serial communications */
    Wire.begin();
    notecard.begin();

    /* Configure Notecard */
    J *req = notecard.newRequest("hub.set");
    JAddStringToObject(req, "product", PRODUCT_UID);
    JAddStringToObject(req, "mode", "continuous");
    JAddStringToObject(req, "sn", "stm32-micromod-v20-SN0001");
    notecard.sendRequest(req);

    /* Configure DFU settings */
    req = notecard.newRequest("card.dfu");
    JAddStringToObject(req, "name", "stm32-bi"); /* bi == boot inversion */
    JAddBoolToObject(req, "on", true);
    notecard.sendRequest(req);
}

void loop()
{
    /* Fast Blink LED while waiting for DFU. */
    Serial.println("Hello, world!");
    digitalWrite(ledPin, HIGH);
    delay(100);
    digitalWrite(ledPin, LOW);
    delay(400);
}

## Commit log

2022-06-16 Initial Commit.
    Added Notecard part in library. Edited symbol to fit style guidelines.
    Added Notecard and MMFB connectors.
    [SparkFun_MicroMod_Function_Board_Blues_Notecarrier.brd, SparkFun_MicroMod_Function_Board_Blues_Notecarrier.sch]
2022-06-23 Board nearly complete, nearing readiness for design review.
    [SparkFun_MicroMod_Function_Board_Blues_Notecarrier.brd, SparkFun_MicroMod_Function_Board_Blues_Notecarrier.sch]
2022-06-23 Board routing complete.
    Initial routing complete, now finishing silk.
    [SparkFun_MicroMod_Function_Board_Blues_Notecarrier.brd, SparkFun_MicroMod_Function_Board_Blues_Notecarrier.sch]
2022-06-23 Initial Silk completed.
    May add Blues Wireless logo.
    [SparkFun_MicroMod_Function_Board_Blues_Notecarrier.brd, SparkFun_MicroMod_Function_Board_Blues_Notecarrier.sch]
2022-06-23 Added measures on board.
    [SparkFun_MicroMod_Function_Board_Blues_Notecarrier.brd]
2022-06-23 Add production notes on board file.
    [SparkFun_MicroMod_Function_Board_Blues_Notecarrier.brd]
2022-06-23 Added micromod silks.
    [SparkFun_MicroMod_Function_Board_Blues_Notecarrier.brd]
2022-06-24 Post DR updates.
    Schematic:
    Add Text to VREG
    Add Text to Notecard
    add 100 ohm resistor on pwr ctrl
    Change Q1/Q3 transistors
    Add Text to jumpers
    Move V_USB on Notecard
    Board:
    Remove L2/L15
    Add units for measures
    Remove underscores from Silks
    Move EWP via over
    Remove copper layer notes
    Give silk labels correct pointers
    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
    [SparkFun_MicroMod_Function_Board_Blues_Notecarrier.brd, SparkFun_MicroMod_Function_Board_Blues_Notecarrier.sch]
2022-06-24 Change one trace for ground pour.
    [SparkFun_MicroMod_Function_Board_Blues_Notecarrier.brd]
2022-06-24 Add protos production files.
    [SparkFun_MicroMod_Function_Board_Blues_Notecarrier-Panel.GBL, SparkFun_MicroMod_Function_Board_Blues_Notecarrier-Panel.GBO, SparkFun_MicroMod_Function_Board_Bl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]
2022-06-27 Deleted extra v-score text in panel.
    [SparkFun_MicroMod_Function_Board_Blues_Notecarrier-Panel.brd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]
2022-08-16 Add PROD_ID to M.2 Connector for Notecard.
2022-08-18 Update to v02.
    Remove 10k PUR on AUX_EN
    Add P-ch FET switch to AUX_EN
    Rear Silk
    Add Notecard SVG to silk
    Change Title of Reset Section of Schematic
    Reduce value of AEN LED bias resistor
    Change FC symbol DFU pins to be named FC-centric
    Add RGB neopixel and connect to AUX2
    Add User Button and connect to AUX1
    Add power gating FET for neopixel and connect to AUX3
    Change AUX breakout
    Swap UART RX/TX to match new FC symbol
    [SparkFun_MicroMod_Function_Board_Blues_Notecarrier.brd, SparkFun_MicroMod_Function_Board_Blues_Notecarrier.sch]
2022-08-18 Change footprint to pass board auto checklist
    [SparkFun_MicroMod_Function_Board_Blues_Notecarrier.brd, SparkFun_MicroMod_Function_Board_Blues_Notecarrier.sch]
2022-08-18 Added v02 panel/gerbers.
    [SparkFun_MicroMod_Function_Board_Blues_Notecarrier-Panel.GBL, SparkFun_MicroMod_Function_Board_Blues_Notecarrier-Panel.GBO, SparkFun_MicroMod_Function_Board_Bl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]
2022-08-22 Swap Notecard RX/TX, add missing silk, add diode PROD-ID.
    [SparkFun_MicroMod_Function_Board_Blues_Notecarrier-Panel.brd, SparkFun_MicroMod_Function_Board_Blues_Notecarrier.brd, SparkFun_MicroMod_Function_Board_Blues_No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]
2022-08-24 Rev to v10. Update RGB Silk. Repanelize for changes.
    [SparkFun_MicroMod_Function_Board_Blues_Notecarrier-Panel.GBL, SparkFun_MicroMod_Function_Board_Blues_Notecarrier-Panel.GBO, SparkFun_MicroMod_Function_Board_Bl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]
2022-09-02 Rev v11
    AEN wasn't enabled by default because it was missing a passive. Added passive and rerouted.
    [SparkFun_MicroMod_Function_Board_Blues_Notecarrier-Panel.brd, SparkFun_MicroMod_Function_Board_Blues_Notecarrier.brd, SparkFun_MicroMod_Function_Board_Blues_No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]
2022-09-14 Update pin visibility for dbg.
2022-10-21 Updated to replace EOL caps.
    [SparkFun_MicroMod_Function_Board_Blues_Notecarrier.brd, SparkFun_MicroMod_Function_Board_Blues_Notecarrier.sch]
2022-11-01 DNP unused diode.
    [SparkFun_MicroMod_Function_Board_Blues_Notecarrier.brd, SparkFun_MicroMod_Function_Board_Blues_Notecarrier.sch]

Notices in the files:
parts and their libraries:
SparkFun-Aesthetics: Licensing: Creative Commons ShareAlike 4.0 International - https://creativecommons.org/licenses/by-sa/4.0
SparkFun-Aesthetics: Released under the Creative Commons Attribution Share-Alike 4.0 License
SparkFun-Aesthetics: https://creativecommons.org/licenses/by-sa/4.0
